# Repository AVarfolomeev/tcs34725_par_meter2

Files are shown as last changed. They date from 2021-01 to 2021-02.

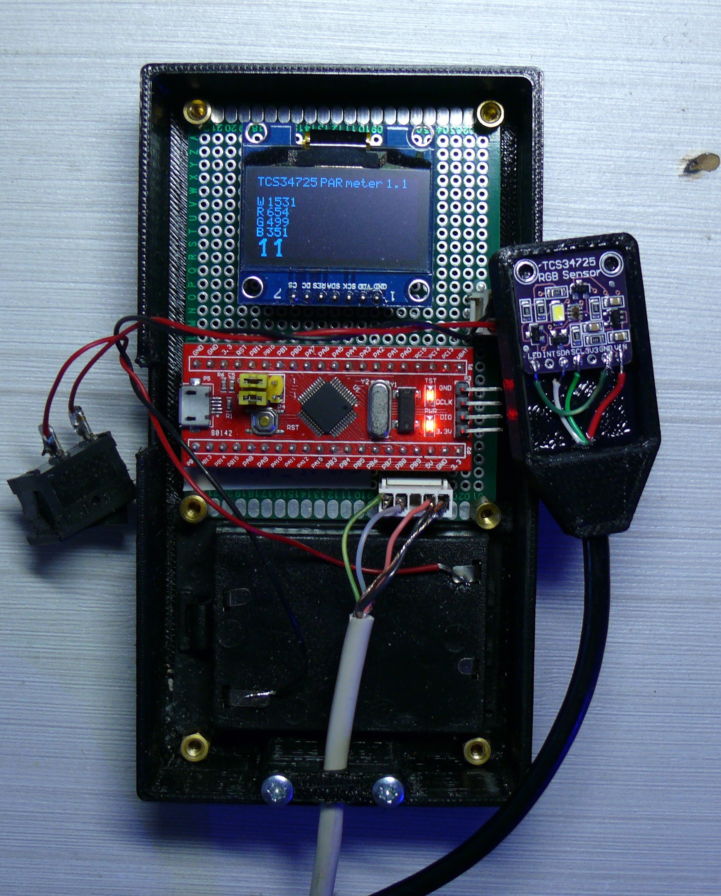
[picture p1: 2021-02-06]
Documentation/Device.jpg

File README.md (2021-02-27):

This is simple PAR-meter based on ambient light sensor TCS34725.

It use blue pill board with STM32F103C8T6 MCU and 1.3" OLED screen.

To compile firmware, use STM32CubeIDE from ST.
To flash firmware, use ST-Link and ST-Link utility from ST.

Default calibration based on sensor sensivity data from TCS34725 datasheet, and works for bare sensor without cover, diffuser, etc...

This firmware provides USB virtual COM port for manual calibration - for Windows, install VCP driver from ST, connect USB port of blue pill
to PC, and open COM port in terminal software like PuTTY. 
Press Enter to show current calibration settings, and short list of supported console commands.

The PAR value calculated by formula:

PAR = K * (Clear * W + Red * R + Green * G + Blue * B), the K W R G - calibration koefficients, Clear, Red, Green, Blue - readed values from sensor,
normalized from 0..max counts [(256 - integration time) * 1024, max 65535] to 0..1 range.

By default, color channels of sensor not used for PAR calclulation, i.e. (W R G B) = (1 0 0 0).

To build, unpack source project into new folder this way:

c:\tcs_workspace\par_meter\par_meter.ioc 
c:\tcs_workspace\par_meter\.cproject
....
and open folder c:\tcs_workspace as workspace in STM32CubeIDE
then File->Import->General->Existing Projects into Workspace, select folder "c:\tcs_workspace\par_meter".

the project folder must be named "par_meter", otherwise STM32CubeIDE can't recognize file par_meter.ioc.

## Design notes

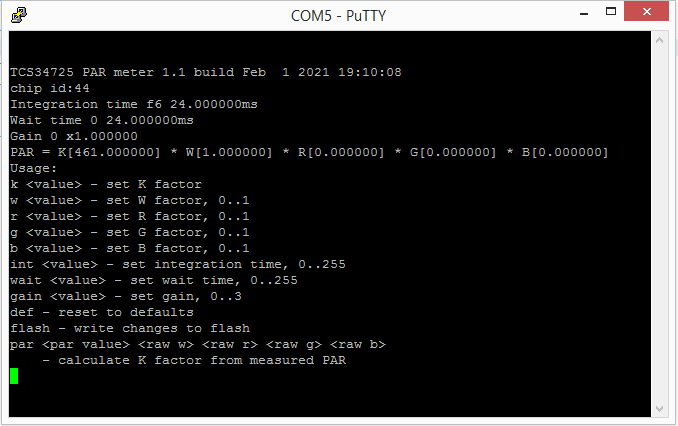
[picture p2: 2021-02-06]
Documentation/cdc.png

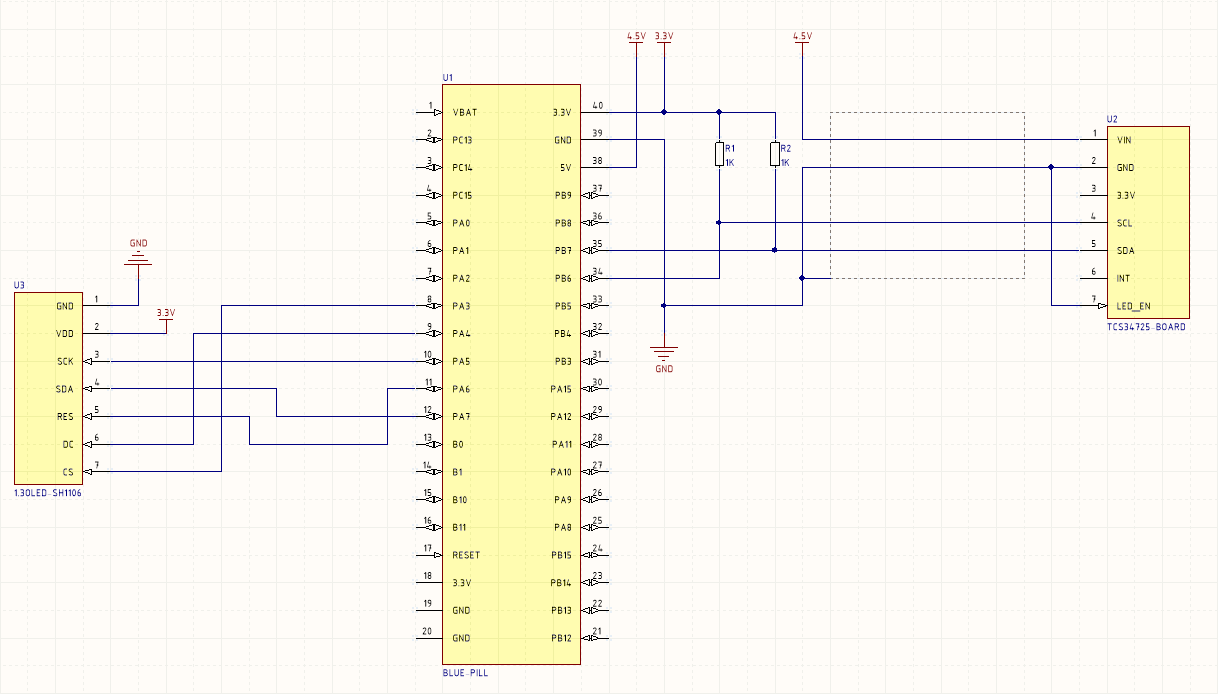
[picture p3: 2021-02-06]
Documentation/Circuit.png

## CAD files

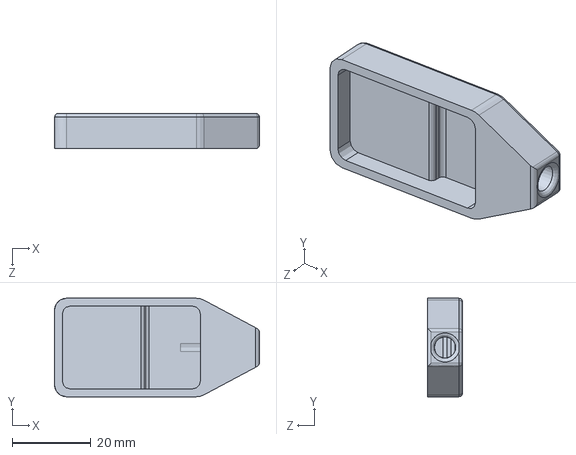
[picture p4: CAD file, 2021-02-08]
Documentation/SensorBodyEx.SLDPRT
52.0 x 25.0 x 9.00 mm

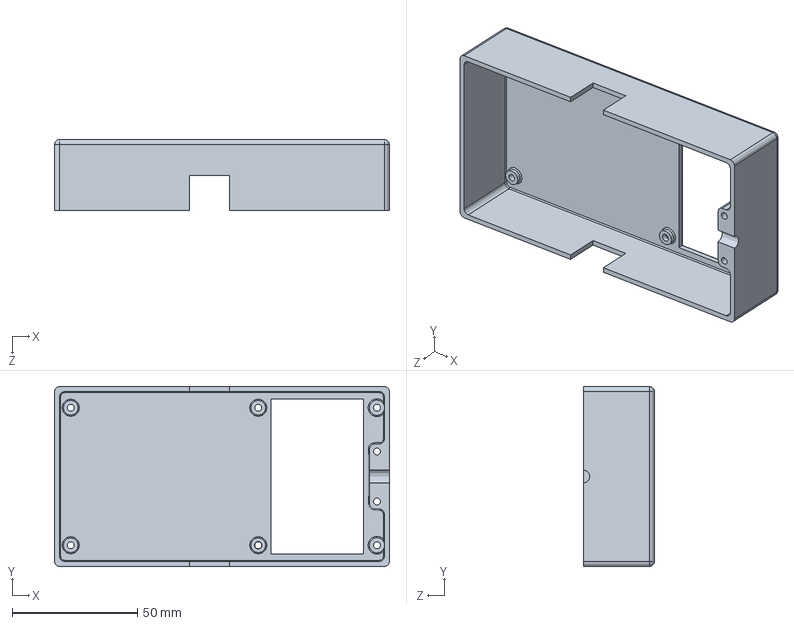
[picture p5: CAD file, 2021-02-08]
Documentation/ParMeterBody.SLDPRT
134.0 x 72.0 x 28.5 mm

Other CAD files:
Documentation/ParMeterBody.STL
Documentation/SensorBodyEx.STL

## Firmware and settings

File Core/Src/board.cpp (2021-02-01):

/*
 * board.cpp
 *
 *  Created on: Dec 25, 2020
 *      Author: andrey
 */
#include <ctype.h>
#include <stdarg.h>
#include "board.h"
#include "usbd_cdc_if.h"
#include "spi1106.h"
#include "settings.h"

extern I2C_HandleTypeDef hi2c1;
extern USBD_HandleTypeDef hUsbDeviceFS;

static volatile bool i2c_tx_completed = false;
static volatile bool i2c_rx_completed = false;

const uint32_t flash_settings_page = 0x0800F7C2;
static settings current_settings;

const auto app_title = "TCS34725 PAR meter 1.1";

void HAL_I2C_MasterTxCpltCallback(I2C_HandleTypeDef *hi2c)
{
	i2c_tx_completed = true;
}

void HAL_I2C_MasterRxCpltCallback(I2C_HandleTypeDef *hi2c)
{
	i2c_rx_completed = true;
}

void i2c_write(uint8_t *pData, uint16_t Size)
{
	//i2c_tx_completed = false;
	//if (HAL_I2C_Master_Transmit_DMA(&hi2c1, 0x29 << 1, pData, Size) != HAL_OK)
	if (HAL_I2C_Master_Transmit(&hi2c1, 0x29 << 1, pData, Size, 1000) != HAL_OK)
	{
		return;
	}

	//while (!i2c_tx_completed);
}

void i2c_read(uint8_t *pData, uint16_t Size)
{
	//i2c_rx_completed = false;
	//if (HAL_I2C_Master_Receive_DMA(&hi2c1, 0x29 << 1, pData, Size) != HAL_OK)
	if (HAL_I2C_Master_Receive(&hi2c1, 0x29 << 1, pData, Size, 1000) != HAL_OK)
	{
		return;
	}

	//while (!i2c_rx_completed);
}

void i2c_write_register(uint8_t reg, uint8_t data)
{
	uint8_t buf[2];
	buf[0] = reg |= 0x80;
	buf[1] = data;

	i2c_write(buf, 2);
}

uint8_t i2c_read_register(uint8_t reg)
{
	reg |= 0x80;

	i2c_write(&reg, 1);

	uint8_t res = 0;
	i2c_read(&res, 1);

	return res;
}

uint32_t i2c_read_word(uint8_t reg)
{
	reg |= 0xA0;

	i2c_write(&reg, 1);

	uint8_t res[2];
	i2c_read(res, 2);

	return (uint32_t)(res[1] << 8) + (uint32_t)res[0];
}

const uint32_t log_buf_size = 512;
char log_buf[log_buf_size];

void log(const char* format, ...)
{
	auto hcdc = (USBD_CDC_HandleTypeDef*)hUsbDeviceFS.pClassData;
	if (hcdc == nullptr)
	{
		return;
	}

	va_list args;
	va_start(args, format);
	int nn = vsnprintf(log_buf, log_buf_size, format, args);
	va_end(args);

	while (hcdc->TxState != 0)
	{
		HAL_Delay(1);
	}
	CDC_Transmit_FS((uint8_t*)log_buf, nn);
}

void read_par()
{
	auto white = i2c_read_word(0x14);
	auto red = i2c_read_word(0x16);
	auto green = i2c_read_word(0x18);
	auto blue = i2c_read_word(0x1a);

	//log("w:%d r:%d g:%d b:%d\n\r", white, red, green, blue);

	const uint32_t buf_size = 64;
	uint8_t y = 2;
	char buf[buf_size];

	snprintf(buf, buf_size, "W %d        ", (int)white);
	sh1106SmallPrint(0, y++, (uint8_t *)buf);

	snprintf(buf, buf_size, "R %d        ", (int)red);
	sh1106SmallPrint(0, y++, (uint8_t *)buf);

	snprintf(buf, buf_size, "G %d        ", (int)green);
	sh1106SmallPrint(0, y++, (uint8_t *)buf);

	snprintf(buf, buf_size, "B %d        ", (int)blue);
	sh1106SmallPrint(0, y++, (uint8_t *)buf);

	double par = current_settings.m_total_factor * current_settings.calc_normalized_from_raw(white, red, green, blue);
	//double par = (double)white * (double)0.045067;
	int ipar = par;
	snprintf(buf, buf_size, "%d        ", ipar);
	sh1106MediumPrint(0, y++, (uint8_t *)buf);
}

void send_status()
{
	log("\n\r\n\r%s build %s %s\n\r", app_title, __DATE__, __TIME__);

	auto chip_id = i2c_read_register(0x12);
	log("chip id:%X\n\r", chip_id);

	log("Integration time %x %lfms\n\r", current_settings.m_integration_time, current_settings.get_integration_time());
	log("Wait time %x %lfms\n\r", current_settings.m_wait_time, current_settings.get_wait_time());
	log("Gain %x x%lf\n\r", current_settings.m_gain, current_settings.get_gain());
	log("PAR = K[%lf] * W[%lf] * R[%lf] * G[%lf] * B[%lf]\n\r",
			current_settings.m_total_factor,
			current_settings.m_white,
			current_settings.m_red,
			current_settings.m_green,
			current_settings.m_blue);
	log("Usage:\n\r");
	log("k <value> - set K factor\n\r");
	log("w <value> - set W factor, 0..1\n\r");
	log("r <value> - set R factor, 0..1\n\r");
	log("g <value> - set G factor, 0..1\n\r");
	log("b <value> - set B factor, 0..1\n\r");
	log("int <value> - set integration time, 0..255\n\r");
	log("wait <value> - set wait time, 0..255\n\r");
	log("gain <value> - set gain, 0..3\n\r");
	log("def - reset to defaults\n\r");
	log("flash - write changes to flash\n\r");
	log("par <par value> <raw w> <raw r> <raw g> <raw b>\n\r");
	log("    - calculate K factor from measured PAR\n\r");
}

const uint32_t cmd_buf_size = 512;
char cmd_buf[cmd_buf_size];
char current_cmd_buf[cmd_buf_size];
uint32_t cmd_input_size = 0;
char* current_cmd = nullptr;

void process_cdc_input(char c)
{
	c = tolower(c);

	if (c == '\r')
	{
		cmd_buf[cmd_input_size] = 0;

		memcpy(current_cmd_buf, cmd_buf, cmd_input_size + 1);
		current_cmd = current_cmd_buf;

		cmd_input_size = 0;
	}
	else if (c == '\b')
	{
		if (cmd_input_size > 0) cmd_input_size--;
	}
	else
	{
		cmd_buf[cmd_input_size] = c;
		cmd_input_size++;
	}

	if (cmd_input_size >= cmd_buf_size)
	{
		cmd_input_size = 0;
	}
}
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

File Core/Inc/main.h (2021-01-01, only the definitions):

#define OLED_CS_Pin GPIO_PIN_3
#define OLED_CS_GPIO_Port GPIOA
#define OLED_DC_Pin GPIO_PIN_4
#define OLED_DC_GPIO_Port GPIOA
#define OLED_RES_Pin GPIO_PIN_6
#define OLED_RES_GPIO_Port GPIOA

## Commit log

2021-02-01 calibration via usb cdc
2021-02-08 3d models
    [ParMeterBody.SLDPRT, ParMeterBody.STL, SensorBodyEx.SLDPRT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]

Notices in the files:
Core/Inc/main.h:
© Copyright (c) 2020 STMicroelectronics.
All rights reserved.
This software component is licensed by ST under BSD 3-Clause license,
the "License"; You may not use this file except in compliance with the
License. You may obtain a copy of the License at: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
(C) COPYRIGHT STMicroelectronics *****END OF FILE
